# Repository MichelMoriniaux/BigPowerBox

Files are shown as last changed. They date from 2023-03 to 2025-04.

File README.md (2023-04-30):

# BigPowerBox
 An open source power distribution switch for 12V DC applications
- [BigPowerBox](#bigpowerbox)
  - [Introduction](#introduction)
  - [USB ports or rather, the lack of](#usb-ports-or-rather-the-lack-of)
  - [File contents](#file-contents)
  - [Requirements](#requirements)
    - [Operate](#operate)
    - [Build](#build)
  - [PCB picture](#pcb-picture)
  - [Enclosure](#enclosure)
  - [N.I.N.A Screencap](#nina-screencap)
- [Acknowledgements](#acknowledgements)

## Introduction
Astrophotography is great hobby but some of its drawbacks are that you often need to hang out in the cold and drive to far away places to find dark skies. Both of these problems can be solved with remote observing, either from your comfortable office while your telescope is out in the cold backyard or far away in a remote observatory. In both cases you may need to power-off-and-on-again equipment to reboot it or simply to shut down your observatory for the day. To this end you can buy specialized equipement to do so or build your own! 

But why would you build vs buy??? 

For one, specialized power boxes are usually expensive (400 to 1000 USD range) and may not provide the features you actually need. Secondly - and most importantly in my case - all the commercial offerings absolutely insist on providing the output ports on 2.5mm barrel connectors. These connectors' fit are notoriously unreliable and in the case of astronomy with a moving mount pulling and tugging on cables is a recipe for frustration and lost imaging time.  
The *BigPowerBox* aka *PowerBox Exxxtreme* is built with versatility, reliability and scale in mind. The output connectors are all GX-12 aviation plugs, most high quality mounts on the market use these plugs as they *screw-on* and provide a very secure connection. A few years back, frustrated by disconnects during slews I replaced all the connectors ( including serial and USB ) with Gx-12s in my EQ-6, this was the origin of my love for these connectors.  
I also found that the commercial powerboxes were also limited in ports, so I went overboard and crammed as much as I could in a small footprint. The box provides natively 14 12V output ports, you could customize these with small buck converters to 5V or whatever voltage mix you would want. There is enough space in the enclosure for that and as an example I have used 2 of the 12v switchable ports to feed at [5v buck converter](https://www.amazon.com/gp/product/B0BHR3RYPS) and a [3A capable USB port](https://www.amazon.com/gp/product/B087RHWTJW) ( great to power a ASIAir or other Raspberry Pi based computers for eg ) 

Building this box was also an exercise in learning a new hobby: electronics design. I'm a CS engineer, not EE. I have built a lot of Arduino based tools ( flip flat panel, temperature regulators for my cheap wine fridges, my own 3d printer and a slew of home automation devices ) but never a device that needed me to read datasheets for. So even though I tested the device I guarantee nothing and do not blame me if it burns down your stuff. I release this as Open Source Hardware with a CERN license so that real HW designers can improve on my base design and point out my noob mistakes. I had my boards fabricated by JLCPCB for about 100USD a piece.

This repo contains all the necessary files to build and control a power box with the following features

- 12V dc 30A input through an XT-60 port
- 14 power ports
  - 2 always-ON ports up to 10A each - use these to connect your NUC or other PC as well a s USB hub
  - 8 switchable ports up to 6.5A each - connect your cameras, mount, focusers, rotators, dust-caps, etc...
  - 4 PWM ports up to 6.5A each - dew-heaters, flat panels or add filtering caps if you want to make them adjustable voltage ports
- expansion RJ12 port for i2c accessories
  - currently only SHT31 Temperature/Humidity probe is supported
- reverse polarity protection on input and outputs
- overcurrent protection
- configurable overvoltage protection ( set in code at 14.4V )
- input Current and voltage measurement
- output current measurement on all ports
- dew heater control based on temp/humid sensors 

## USB ports or rather, the lack of
All commercial powerboxes have an integrated USB hub, so why does my box not have one? TBH I originally wanted to also have an awesome USB3.1 Gen 2 hub with plenty of ports, but have you ever tried to design one? One of the goals was to spend less building this than buying a commercial box and from my research - and the laughs of my friends who are in hardware - I deduced that I would have spent much more just iterating to get the high speed USB hub working. It's a completely different ball game to build a reliable, superspeed USB hub, especially when astrophotographers looove long usb cables. So I decided to leave that project for another day and just buy an industrial hub.

## File contents
Please read the Readme in each folder for more details

- Arduino
  - BigPowerBox   -  Arduino firmware
- Drivers
  - BigPowerSwitchServer  -  Visual Studio 22 solution to build the ascom COM server driver
  - IndiBigPowerSwitch - TODO: Indi driver
- Hardware
  - Enclosure - Case STL + link to Fusion 360 model
  - PCB - Gerber files to have the board manufactured, BOM and placement files, Electric schematics, EasyEDA project files

## Requirements
### Operate
To Operate this device you will need the following
- Windows
  - Ascom platform
  - FTDI driver ( my arduino implementation uses a FT232 chip)
  - Astro sequencer ( I tested on N.I.N.A but this should also work on SGP and others )
  - download the ascom installer from the [releases](https://github.com/MichelMoriniaux/BigPowerBox/releases) tab and run it, the Switch will be available in your Ascom chooser under "ShortCircuit.BigPowerSwitch"
- Linux (TODO)
  - Indi platform
  - Kstars / Ekos

### Build
To build the device you will need:
- a spare arduino with an ICSP cable ( to burn the bootloader ). I used an arduino nano from which I cut the traces to the RESET pin on the ICSP header and soldered it to pin D10. Replaced the header with a set of pogo pins and done.
  - [Pogo pins](https://www.amazon.com/gp/product/B075Q25BK3)
  - [Arduino](https://www.amazon.com/gp/product/B0713XK923)
- Arduino dev environment  
- 3d printer + slicer
- [M3 8mm flat head bolts](https://www.amazon.com/gp/product/B07WZL3Z7H)
- [M3 inserts](https://www.amazon.com/gp/product/B08YYGRCBG)
- [GX12 connectors](https://www.amazon.com/gp/product/B01MPXOOI3)
- [SHT31](https://www.amazon.com/gp/product/B07ZSZW92J)
- [XT60 connectors](https://www.amazon.com/gp/product/B07Q2SJSZ1)  

To Customize the software you will additionally need:
- for ASCOM the Ascom dev platform and Visual Studio 2022
- for Linux Indi and build-tools  

To customize the hardware you will also need:
- EasyEDA

## PCB picture
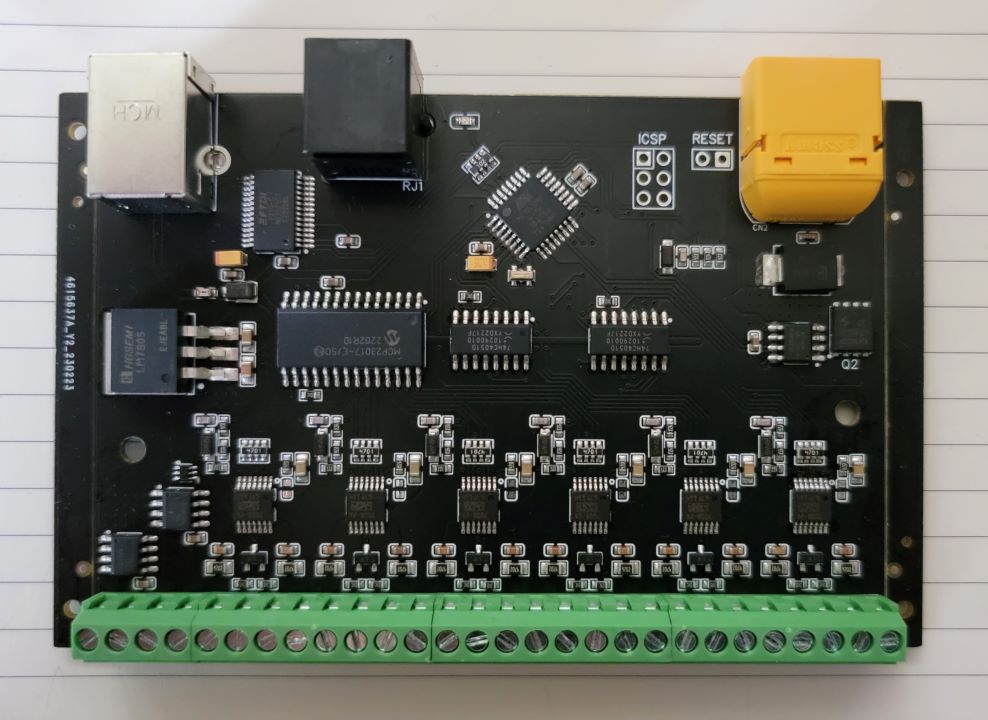
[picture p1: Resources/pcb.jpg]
PCB Picture


## Enclosure
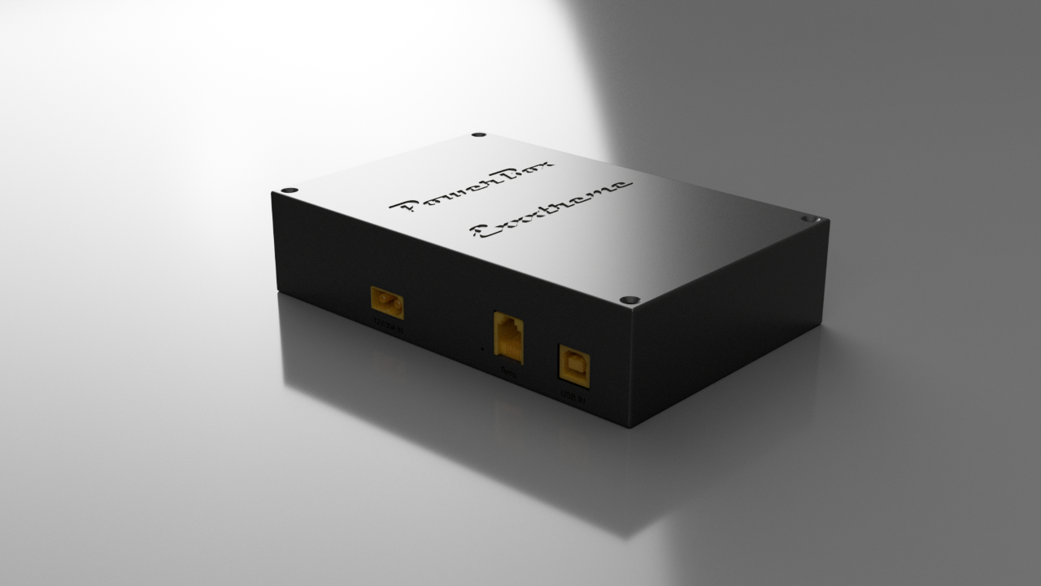
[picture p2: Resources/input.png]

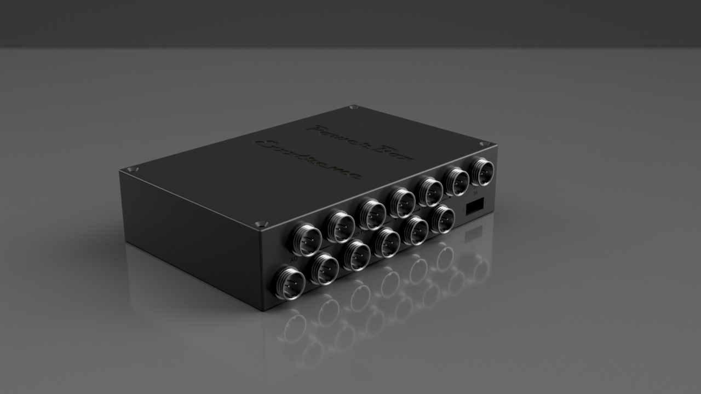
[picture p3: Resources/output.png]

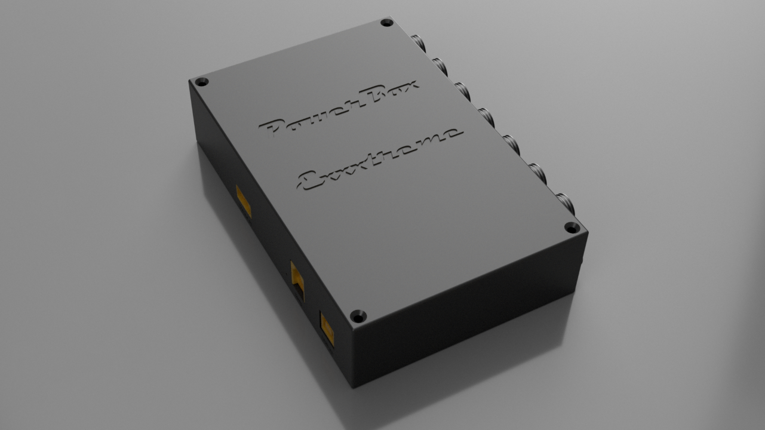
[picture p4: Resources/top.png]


## N.I.N.A Screencap
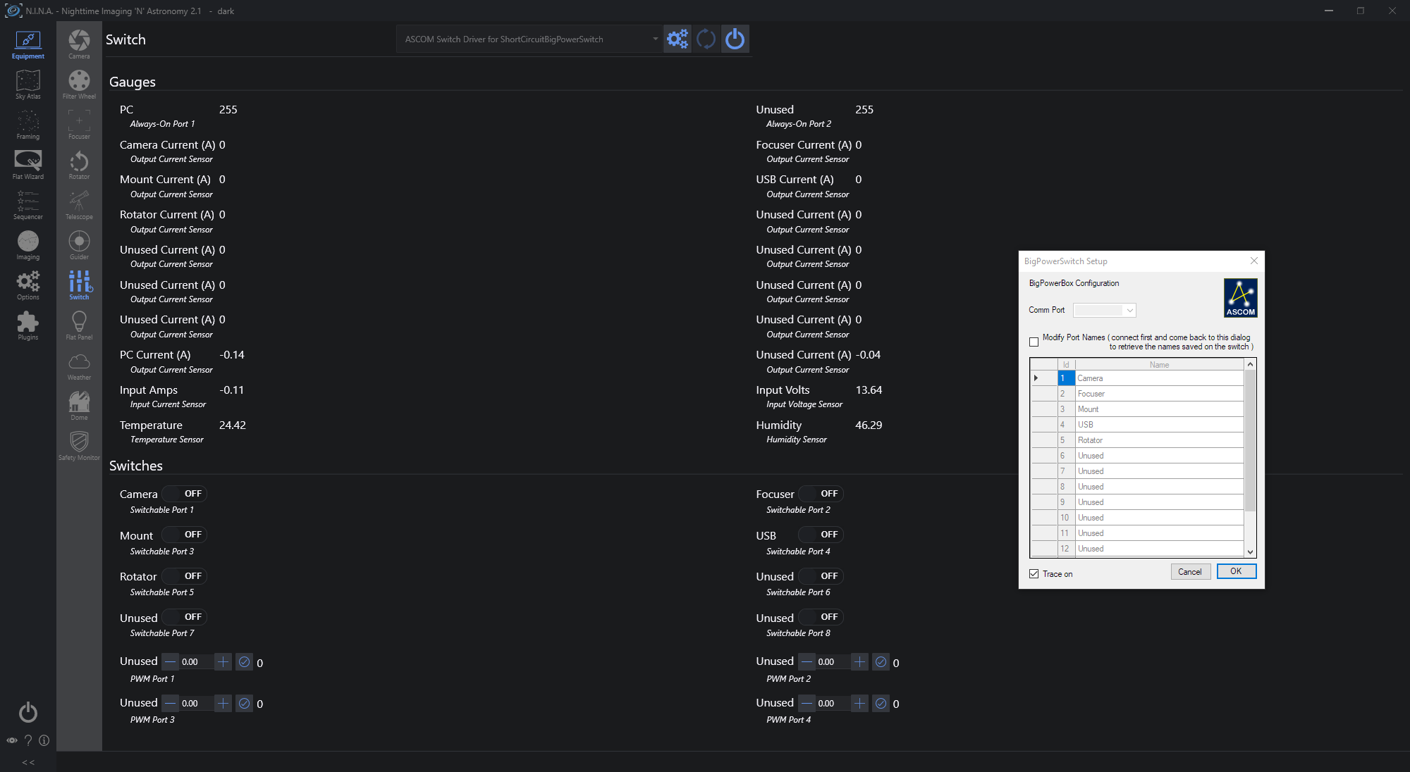
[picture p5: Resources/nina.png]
screencap


# Acknowledgements
The first electronic project I built and customized was [MyfocuserPro2](https://sourceforge.net/projects/arduinoascomfocuserpro2diy/) by [Robert Brown](rbb1brown@gmail.com), reading and customizing the code for my version of the focuser introduced me to Arduino programming and pushed me to build my 3d printer. I encourage you to go check that project out.

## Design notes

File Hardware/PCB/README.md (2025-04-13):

# BigPowerBox
 An open source power distribution switch for 12VDC applications

# Introduction
The BigPowerSwitch is a 12V DC distribution switch that allows individual control and measurement of 14 DC ports. It should be able to drive 30A of current to the output ports with a maximum of 6.5 amps on each port. It is not recommended to drive the board that high as the thermals have not been tested to that level. It should function correctly for the usual loads pulled by astronomy cameras and accessories.

# Implementation
The BigPowerSwitch has the following components:
- PCB
  - 4 layer 
    - top layer signal + GND flood
    - uninterrupted 1 Oz 12V flood ( do a 2Oz if you can. Also might be better to swap this one with plane 3 for future add of USB3.1 - impedance )
    - uninterrupted 1 Oz GND flood
    - bottom layer via signals + GND flood
- Input stage
  - XT60 connector for 30A capability, polarity protection and snug connection. Also pretty much the standard for RC stuff so I have good experience with and love those connectors. If it can survive sustaining multiple Gs followed by a crash while pulling 30Amps it should work for astro gear. I would have prefered a screwable connector but could not find a good option, also having a different polarized connector can prevent mistakes.
  - 33V TVS diode
  - 20V 60A Mosfet to protect against reverse voltage input ( backwards connection to a battery )
  - 30A Ammeter feeding a dedicated ADC port on the microcontroller ( In Amps )
  - 15V to 5V voltage divider feeding a dedicated ADC port in the microcontroller ( In Volts )
- Output stages
  - uses the 12V plane
  - 6 Infineon BTS7008-2EPA 2 channel high switches
    - 4 for switch ports ( 8 ports ) enable pins through port expander MCP23017
    - 2 for PWM control ( 4 ports ) enable pins directly driven by microcontroller digital PWM pins
    - diagnostic pin for Current sensing feeding a multiplexed ADC pin on the microcontroller
    - I chose Infineon as they seem to be an automotive supplier and thus heavier duty than my original thought of using TI backplane chips.
  - 2 10A Ammeters for always-on ports feeding a multiplexed ADC pin on the microcontroller. Here I used CrossChip, the LCSC part choser only gave this reference for a 10A ammeter, datasheet needed to be translated as not available in English...
  - 5V/1A voltage regulator for VCC
  - DB125 screw terminals
- Control
  - Arduino nano V3 implementation
    - Atmel 328P microcontroller
    - FT232RL USB serial controller
    - 1 power LED ( yep Tx and Rx leds are just luminous noise, even this one is overkill )
    - ICSP port
    - i2c bus with RJ12 output for temp/humid sensor
  - MCP23017 i2c I/O port expander
    - controls the enable pins of the on/off switches (EN0 and EN1 on BTS7008-2EPA)
    - uses the 8 GPA pins. 8 pins (GPB) unused
  - 2 74HC4051D multiplexers
    - one for output: distributes the DSEL signal to select the diagnosed port on the Infineon switches
    - one for input: collects the diagnostic signal from the Infineon switches and output port ammeters to a single ADC pin on the microcontroller
    - both function in parallel driven by the same 3 control pins on the microcontroller

All resistor and capacitor values were chosen based on datasheet recommendations and prototyping sample board specifications. I'm pretty sure I could have used more decoupling caps.

The board was designed in EasyEDA with the LCSC for JLCPCB parts catalog and fabricated by JLCPCB. This PCB prototyper has a minimum of 5 boards runs for PCB production and 2 boards for assembly, the run for 5 boards and 2 assemblies was less than 250USD delivered.

I have provided in this repo:
- the Gerber files to produce the PCB
- the EasyEDA source files with the schematics and PCB layout
- BoM file
- placement file for assembly

Once the board delivered, you will need to flash a bootloader onto it. There are a lot of guides on the web as how to do this but it essentially boils down to: in the Arduino IDE, configure the board as an "Arduino Nano", processor as "ATMega 328P" and Programmer as "Arduino as ISP", connect the ISCP cable from your burner and click "Burn Bootloader"  
You can build a quick and dirty burner from an arduino nano board, a 2cm piece of wire, a knife and some pogo pins.  

# PCB image and Finished product
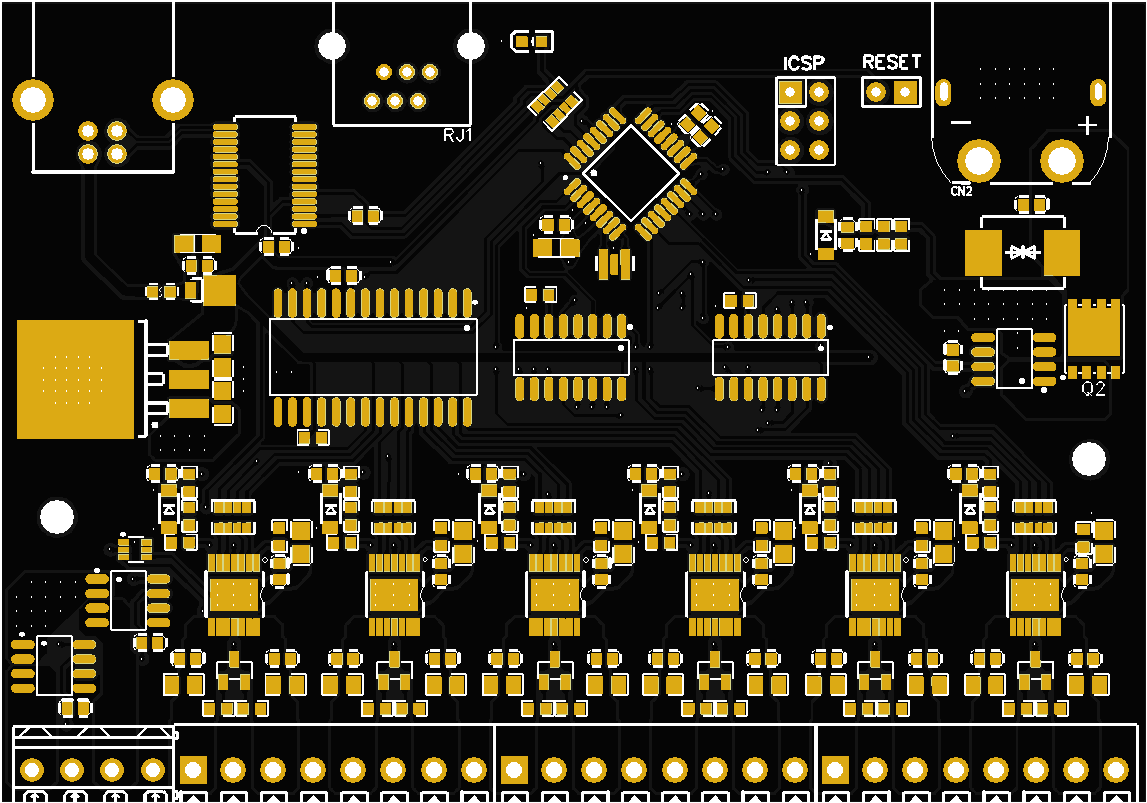
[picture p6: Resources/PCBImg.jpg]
PCB

PCB Picture

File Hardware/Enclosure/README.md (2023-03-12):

# BigPowerBox
 An open source power distribution switch for 12VDC applications

Here you will find STLs for the box and lid.  
The box is configured to be printer friendly and has 13 GX12 ports and one USB port.  
2 Allways-on, 6 Switch ports, 4 PWM ports, 1 5V port, 1 USB port (power only)

The Enclosure Fusion360 source file is [here](https://a360.co/3Ja40tm)

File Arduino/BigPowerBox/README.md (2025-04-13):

# BigPowerBox Arduino Firmware
An open source power distribution switch for 12VDC applications

Please see the README for the hardware before reading this file
- [BigPowerBox Arduino Firmware](#bigpowerbox-arduino-firmware)
- [Introduction](#introduction)
- [Logic](#logic)
- [Required Libraries](#required-libraries)
- [Modularity](#modularity)
- [Hardware expansion](#hardware-expansion)
- [Temperature probes](#temperature-probes)
- [Storage](#storage)
- [Command Protocol](#command-protocol)
  - [Available commands:](#available-commands)
- [Building Options](#building-options)

# Introduction
This is the firmware for the BigPowerBox. It manages input commands and provides status updates to the driver. The Powerbox can function standalone without a USB connection to a host.

# Logic
The firmware for the power box is built as a state machine.
The state machine starts in an ***idle*** state. Every loop cycle it verifies if there is a command in queue and processes it.
Every *REFRESH* milliseconds the state changes to ***read***.
In ***read*** state the firmware polls the arduino ADC pins for values and verifies if the input voltage is below the shutdown value. If the input voltage is above, it calls a function to shutdown all the switchable and PWM output ports.
Once the values are read the FSM moves to ***dew*** state where it reads temperatures and adjusts the configured PWM ports. Once this is done the FSM goes to the ***swap*** state and uses the PCB's multiplexers to select the next port to read the output Current from. Once the swap is executed the FSM returns to ***idle*** state.

When a command is sent to the controller it is pushed into a LIFO queue. At each loop the code checks if there are commands in queue and if yes pops one command and processes it.

# Required Libraries
To build you will need to install the following packages into your Arduino Libraries:  
***EEPROM***      should be included by default in your base install  
***Wire***        One Wire Lib for i2c  
***Adafruit_MCP23XXX*** to operate the MCP23017 i2c controlled I/O expander on the board  
***Adafruit_SHT31*** for SHT3x temperature/humidity sensor  
***Adafruit_AHTX0*** for the cheap AHT10 temperature/humidity sensor
***Adafruit_BME280*** for the BME280 temperature/humidity/pressure sensor
***SparkFun_I2C_Mux_Arduino_Library*** for the PCA9548A i2c multiplexer
***PIDController*** for the PWM dew heater PID control
***[MemoryFree](https://github.com/mpflaga/Arduino-MemoryFree)*** only for debug purposes ( used it to make sure I was not fragmenting the memory )

# Modularity
I originaly wanted this code to be generic and customizable for any board layout by only customizing *board.h*. This is still a work in progreass as I took shortcuts to get a working prototype out. The main variable is the boardSignature string that defines the list of ports, their order and their types. This also defines how the status string is presented. The following comment in *board.h* defines the boardSignature:

    // Board signature
    //  s: arduino addressable switchable port
    //  m: multiplexed switchable port
    //  p: pwm port
    //  a: Allways-On port
    //  f: Temp/Humidity probe
    //  g: Temp/Humidity/pressure probe
    //  t: temperature probe
    //  h: humidity probe
    // always-on ports always last followed by t then h
    const String boardSignature = "mmmmmmmmppppaath";

# Hardware expansion
The board is expandable through the exposed i2c interface via the RJ12 connector. Currently are supported BME280, SHT31, AHT10 and the PCA9548A i2c multiplexer, allowing you to build complex temperature probe setups. The setups allow you to either have a simple Temperature / Humidity sensor to turn on the configured PWM ports when the temperature dips below the dewpoint or have a more complex setup with dedicated temperature feedback for each PWM port (adjusting each port output to maintain a configurable temperature offset above the dewpoint).  
The RJ12 port has the following pinout  

    pin 1: NC
    pin 2: GND
    pin 3: SDA
    pin 4: SCL
    pin 5: 5V
    pin 6: NC

# Temperature probes
The board will detect i2c temperature probes at boot. The first probe found will always be the global environment probe, each additional probe found will be assigned to the PWM ports in ascending order for PID control. the order of preference for primary probe is BME280, SHT31, AHT10

# Storage
The EEPROM on the Atmel328 is 1024 bytes and it's cells are limited to 100k writes.  
We reserve the first 16x14 bytes (224 bytes) to store the port names ( this includes the trailing '\0' so port names are limited to 15 chars). We don't expect these to change often so no special scheme is implemented to save write cycles. There is no provision to flag a name as valid, we could have used the first byte and limit the name to 14 chars.  
Starting at byte 224 we store the configuration. The configuration is 18 bytes long and contains the port statuses and a validity flag. The config is saved every time a port changes state. To limit EEPROM wear we write the config to the next 18 following bytes. At startup we need to find this config so that is where the validity flag comes into play.

# Command Protocol
Every command and it's reply starts with a '>' and ends with a '#' 
newlines and carriage returns are not required, fields inside commands are separated by ':' characters

example commands:
|send|reply|
|---|---|
|`>P#`|`>POK#`|
|`>M:01:Hello World#`|`>MOK#`|
|`>N:01#`|`>N:01:Hello World#`|

## Available commands:
|literal|command|response|description|
|---|---|---|---|
|`P`|Ping|`POK`|Ping the device, can be used for autodiscovery of comm ports or to maintain a keepalive for a watchdog|
|`D`|Discover|`D:<Name>:<Version>:<Signature>`|Discover the device and capabilities, returns the following fields
|||`<Name>`|the device name|
|||`<Version>`|hardware revision|
|||`<Signature>`|a string representing the device capabilities|
|`S`|Status|`S:<statuses>:<currents>:<Ic>:<Iv>:<t>:<h>`|The status of all ports and measurements|
||||`<statuses>` is a colon separated list of statuses|
|||| 0: switchable port Off|
|||| 1: switchable port On or always-on port|
|||| 000 to 255: PWM port duty-cycle level|
||||`<currents>` same number of fields as `<statuses>` each indicating the output current in A|
||||`<Ic>` Input Current in A|
||||`<Iv>` Input Voltage in V|
||||`<t>` temperature in C Optional ( only present if the hardware is detected )|
||||`<h>` humidity in % Optional ( only present if the hardware is detected )|
||||`S:0:1:0:1:0:1:005:200:1:1:0.00:5.25:0.00:3.12:0.00:7.09:0.10:2.3:0.00:0.00:15.46:12.4:8.1:75.0`|
||||the example matches the ouput for the signature string example above: 10 status fields `ssmmmmppaa` followed by 10 current fields in the same order followed by the input current, input voltage, temp and humid|
|`N:<dd>`|Get port Name|`N:<dd>:<portname>`|get the stored port name for port `<dd>` ( 2 digit number 0-padded eg `05` or `12`)|
||||`<portname>` 15 character max port name|
|`M:<dd>:<portname>`|Set port name|`MOK`|set the port name `<portname>` of port `<dd>`|
|`O:<dd>`|ON|`OOK`|Turn port `<dd>` On|	
|`F:<dd>`|OFF|`FOK`|Turn port `<dd>` Off|
|`W:<dd>:<level>`|set PWM level|`WOK`|set the port `<dd>` to `<level>` level is an integer between 0 (Off) and 255 (full On)|
|`C:<dd>:<mode>`|set PWM port mode|`COK`|set the port `<dd>` to `<mode>` mode is an integer: |
||||0: pwm adjustable port|
||||1: behave like and ON/OFF port|
||||2: dewpoint mode: when the temperature measured by the reference probe dips below the dewpoint turn on the port to the preset value, turn it off if the temperature rises above the dewpoint. requires a connected temp/humid probe|
||||3: temperature controlled mode: the port has a dedicated temperature probe that allows to turn off the port when the temperature of the dedicated probe rises above the dewpoint |
|`G:<dd>`|get PWM port mode|`G:<dd>:<mode>`|get `<mode>` of the port `<dd>`|
|`T:<dd>:<temp>`|set a positive temperature offset for the dew control fir each PWM port|`TOK`|set `<temp>` offset for port `<dd>`|
|`H:<dd>`|get the temperature offset for a port|`H:<dd>:<temp>`|get `<temp>` offset of the port `<dd>`|

# Building Options
to build and flash the firmware you will need the following:
a pogo pin programmer for the initial bootflash, see the instructions in the PCB folders
For the firmware use the same option as for an Arduino Nano:
- Board: Arduino AVR Boards / Arduino Nano
- Processor: ATMega328P

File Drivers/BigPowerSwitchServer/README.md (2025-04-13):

# BigPowerBox ASCOM Driver
An open source power distribution switch for 12VDC applications

Please see the [README for the firmware](https://github.com/MichelMoriniaux/BigPowerBox/blob/main/Arduino/BigPowerBox/README.md) before reading this file

- [BigPowerBox ASCOM Driver](#bigpowerbox-ascom-driver)
- [Introduction](#introduction)
- [Principles of Operation](#principles-of-operation)
- [Installing the driver](#installing-the-driver)
- [Building the driver](#building-the-driver)

# Introduction
This Ascom driver will work with the open source hardware BigPowerBox or any hardware that respects the BigPowerBox Protocol.

The driver exposes all the power ports and sensors of the device via Ascom Switches. The polling frequency will depend on the client software. For eg. N.I.N.A polls each switch's name and value every 2sec.

The configuration pane allows to set the names of the power ports. Note that upon launch the configuration dialog does not know the names saved on the device, please set the comm port and press OK, connect and then re-access the configuration dialog. The names saved on the device will be populated and will be editable. Any modifications done to the port names prior to connecting to the device will be discarded. Note that the first time you read the port names on a brand new board you will get garbage as the firmware does not initialize the EEPROM at initial boot. Actually there is no mechanism for the firmware to know if a valid name is stored.

# Principles of Operation
The driver is built as a COM server. This allows multiple clients to connect and control the switches concurrently.
The server driver is started when the first client connects. The server connects to the hardware via a USB serial port, retrieves the board description and populates the internal data structures.  
The client polling and hardware polling are decoupled for performance reasons. Once connected the hardware driver starts a polling thread that polls the hardware ( status command ) every ***UPDATEINTERVAL*** seconds ( 2 in the Release version) and updates the internal data structures. When a client requests a port value or status the hardware driver responds with the value stored in the data structure. When a client wants to update a switch the command is directly forwarded to the hardware.  
So in short *Read* operations are asynchronous and *Write* oprations are synchronous.  
The server maintains a list of clients and shuts down once all clients have disconnected.  
You can now configure the PWM ports into 4 modes:
- 0: normal PWM mode
- 1: on/off mode this requires a connect/deconnect in N.i.n.a. for the UI to update
- 2: dew heater mode, when the ambient temperature dips under the dewpoint the associated port will turn on to a preset value
- 3: temperature control, this requires an additional temperature probe for the dew heater and will control the port according to a PID algorithm to set the temperature to dewpoint + configurable offset

# Installing the driver 
Downlad the installer from the [releases](https://github.com/MichelMoriniaux/BigPowerBox/releases) tab and run it, it should register the server and make the driver available in the ASCOM choser. 

# Building the driver
Open the solution in Visual Studio 2022 and press `CTRL+B` the driver should build.  
Open a command prompt and run the local server exe `ASCOM.ShortCircuitBigPowerSwitch.exe` with the `/regserver` parameter (requires admin privileges), which will create the entry that appears in the ASCOM Chooser. This registration only needs to be done once on each PC. Use the `/unregserver` parameter to unregister the server when no longer required. Never use `REGASM` on the local server executable.
Even better modify the included .iss file to match your paths and compile your own installer, .iss files are used with Inno Setup Compiler

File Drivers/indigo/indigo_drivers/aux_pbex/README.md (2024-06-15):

# BigPowerBox driver

https://github.com/MichelMoriniaux/BigPowerBox

## Supported devices
* BigPowerBox

## Supported platforms

This driver is platform independent.

## License

INDIGO Astronomy open-source license.

## Use

indigo_server indigo_aux_pbex

## Status: Stable

Tested with physical device.

## Build instructions
* this driver depends on indigo server. The indigo server code can be downloaded from the github link below -

https://github.com/indigo-astronomy/indigo/tree/master

Alternatively, the binaries are available here -

https://www.indigo-astronomy.org/downloads.html

Additionally, gcc compiler and other build toold are also required.

Once the indigo environment is setup, follow these steps to build the indigo_aux_pbex (BigPowerBox) driver -
* start by compiling indigo_drivers/aux_pbex/indigo_aux_pbex_main.c

  gcc -c indigo_aux_pbex_main.c

  if instead of binaries indigo server code was built then, libindigo.so needs to be added to the LD_LIBRARY_PATH.

* build a shared library

  sudo gcc -fPIC -shared -o /usr/lib/indigo_aux_pbex.so indigo_aux_pbex.c

  by default libindigo exists in /usr/lib/. If the code was built from scratch then the relative library path would be /indigo/build/drivers.

* build executable 

  sudo gcc -o /usr/bin/indigo_aux_pbex indigo_aux_pbex_main.o -l:libindigo.so -l:indigo_aux_pbex.so -lm

* run/load the driver 

  if indigo server was installed directly just run -
  indigo_server indigo_aux_pbex

  if indigo server is built from scratch load the driver either from indigo control panel or from the indigo config web page.

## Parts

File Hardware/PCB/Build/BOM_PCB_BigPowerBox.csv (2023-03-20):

ID | Name | Designator | Footprint | Quantity | Manufacturer Part | Manufacturer | Supplier | Supplier Part | Price
1 | 100nF | C3,C31,C29,C28 | C0603 | 4 | CC0603KRX7R9BB104 | YAGEO(国巨) | LCSC | C14663
2 | DS1133-S60BPX | RJ1 | RJ11-TH_DS1133-S60BPX | 1 | DS1133-S60BPX | CONNFLY | LCSC | C77859 | 0.026
3 | HY15P03C2 | Q2 | DFN-8_L5.9-W5.2-P1.27-LS6.2-BL | 1 | HY15P03C2 | HUAYI(华羿微) | LCSC | C123687
4 | XT60PW-M | CN2 | CONN-TH_XT60PW-M | 1 | XT60PW-M | AMASS(艾迈斯) | LCSC | C98732 | 0.075
5 | 4.7kΩ | RN7,RN6,RN5,RN4,RN2,RN3 | RES-ARRAY-SMD_0603-8P-L3.2-W1.6-BL | 6 | 4D03WGF4701T5E | UNI-ROYAL(厚声) | LCSC | C66697 | 0.002
6 | 16MHz | X1 | OSC-SMD_3P-L3.2-W1.3-P0.95-L | 1 | CSTCE16M0V53-R0 | muRata(村田) | LCSC | C32180 | 0.037
7 | 670688001 | USB1 | USB-B_TH_670688001 | 1 | 670688001 | MOLEX | LCSC | C490687 | 0.16
8 | DB125-3.5-4P-GN | U24 | CONN-TH_DB125-3.5-4P-GN | 1 | DB125-3.5-4P-GN-S | DIBO(地博电气) | LCSC | C2757925 | 0.044
9 | LM7805S/TR | U22 | TO-263-3_L8.6-W10.2-P2.54-LS14.4-BR | 1 | LM7805S/TR | HGSEMI(华冠) | LCSC | C507146 | 0.04
10 | FT232RL-REEL | U21 | SSOP-28_L10.2-W5.3-P0.65-LS7.8-BL | 1 | FT232RL-REEL | FTDI(飞特帝亚) | LCSC | C8690 | 0.937
11 | ATMEGA328P-AU | U20 | TQFP-32_L7.0-W7.0-P0.80-LS9.0-BL | 1 | ATMEGA328P-AU | MICROCHIP(美国微芯) | LCSC | C14877 | 0.499
12 | MCP23017T-E/SO | U19 | SOIC-28_L17.9-W7.5-P1.27-LS10.3-BL | 1 | MCP23017T-E/SO | MICROCHIP(美国微芯) | LCSC | C629440 | 0.407
13 | DB125-3.5-8P-GN-S | U33,U14,U13 | CONN-TH_8P-P3.50_DORABO_DB125-3.5-8P-GN-S | 3 | DB125-3.5-8P-GN-S | DIBO(地博电气) | LCSC | C5184954 | 0.102
14 | 74HC4051D,653 | U17,U12 | SOIC-16_L9.9-W3.9-P1.27-LS6.0-BL | 2 | 74HC4051D,653 | Nexperia(安世) | LCSC | C9386 | 0.041
15 | CC6900SO-30A | U11 | SOP-8_L4.9-W3.9-P1.27-LS6.0-BL | 1 | CC6900SO-30A | CrossChip(成都芯进) | LCSC | C355193 | 0.114
16 | CC6900SO-10A | U8,U7 | SOP-8_L4.9-W3.9-P1.27-LS6.0-BL | 2 | CC6900SO-10A | CrossChip(成都芯进) | LCSC | C286005 | 0.126
17 | BTS70082EPAXUMA1 | U6,U5,U4,U3,U2,U1 | PG-TSDSO-14_L4.9-W3.9-P0.65-LS6.0-BL-EP | 6 | BTS70082EPAXUMA1 | Infineon(英飞凌) | LCSC | C2150060 | 0.901
18 | 1K | RN1 | RES-ARRAY-SMD_0603-8P-L3.2-W1.6-BL | 1 | YC164-JR-071KL | YAGEO(国巨) | LCSC | C93675 | 0.001
19 | 47kΩ | R59,R52,R51,R50,R39,R38,R37,R36,R35,R34,R33,R29 | R0805 | 12 | 0805W8F4702T5E | UNI-ROYAL(厚声) | LCSC | C17713
20 | 47Ω | R49,R48,R43,R42,R41,R40 | R0603 | 6 | 0603WAF470JT5E | UNI-ROYAL(厚声) | LCSC | C23182
21 | 10kΩ | R47,R46,R45,R44,R31,R28,R27,R26,R25,R24,R23,R22,R21,R16,R12 | R0603 | 15 | 0603WAF1002T5E | UNI-ROYAL(厚声) | LCSC | C25804
22 | 1.2kΩ | R74,R71,R68,R65,R32,R11 | R0603 | 6 | 0603WAF1201T5E | UNI-ROYAL(厚声) | LCSC | C22765
23 | 4.7kΩ | R73,R72,R70,R69,R67,R66,R64,R63,R62,R61,R15,R14,R13,R10,R9 | R0603 | 15 | 0603WAF4701T5E | UNI-ROYAL(厚声) | LCSC | C23162
24 | PUMD3,125 | Q1 | SOT-363_L2.0-W1.3-P0.65-LS2.1-BL | 1 | PUMD3,125 | Nexperia(安世) | LCSC | C553517 | 0.009
25 | KT-0603R | LED1 | LED0603-R-RD | 1 | KT-0603R | null | LCSC | C2286
26 | MF-FSMF050X-2 | F1 | F0603 | 1 | MF-FSMF050X-2 | BOURNS | LCSC | C210357 | 0.006
27 | SS1P3L-M3/84A | D11,D3 | DO-220AA_L3.4-W2.0-LS3.9-RD | 2 | SS1P3L-M3/84A | VISHAY(威世) | LCSC | C2875475 | 0.049
28 | BAW56_C181106 | D10,D9,D8,D7,D6,D5 | SOT-23-3_L2.9-W1.3-P1.90-LS2.4-BR | 6 | BAW56 | Hottech(合科泰) | LCSC | C181106 | 0.002
29 | BZT52C5V1_C2891773 | D16,D15,D14,D13,D12,D4,D2 | SOD-123_L2.7-W1.6-LS3.7-R-RD | 7 | BZT52C5V1 | YONGYUTAI(永裕泰) | LCSC | C2891773 | 0.002
30 | SMCJ33CA_C310048 | D1 | SMC_L6.9-W5.9-LS7.9-BI | 1 | SMCJ33CA/TR13 | Brightking(君耀电子) | LCSC | C310048 | 0.019
31 | 4.7uF | C30,C25 | CASE-A_3216 | 2 | TAJA475K016RNJ | Kyocera AVX | LCSC | C7187 | 0.015
32 | 100nF | C47,C20,C19,C18,C17,C16,C15 | C0805 | 7 | CC0805KRX7R9BB104 | YAGEO(国巨) | LCSC | C49678 | 0.001
33 | 330nF | C46 | C0805 | 1 | 0805B334K500NT | FH(风华) | LCSC | C1740 | 0.003
34 | 100pF | C38,C37,C36,C35,C34,C5 | C0603 | 6 | CL10C101JB8NNNC | SAMSUNG(三星) | LCSC | C14858 | 0.001
35 | 4.7nF | C24,C23,C22,C21,C14,C13,C12,C11,C10,C9,C7,C6 | C0603 | 12 | 0603B472K500NT | FH(风华) | LCSC | C53987
36 | 1uF | C45,C44,C43,C33,C32,C27,C26 | C0603 | 7 | CL10A105KB8NNNC | SAMSUNG(三星) | LCSC | C15849 | 0.001
37 | 1nF | C1 | C0603 | 1 | CL10B102KB8NNNC | SAMSUNG(三星) | LCSC | C1588 | 0.001

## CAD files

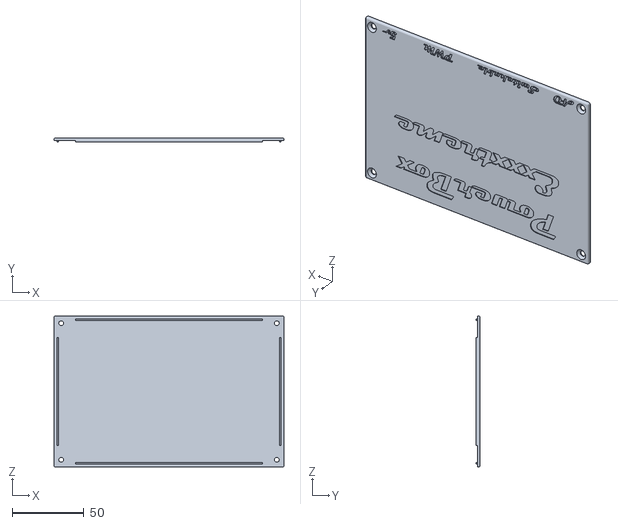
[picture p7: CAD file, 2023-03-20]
Hardware/Enclosure/Lid.stl
160.0 x 3.00 x 105.0

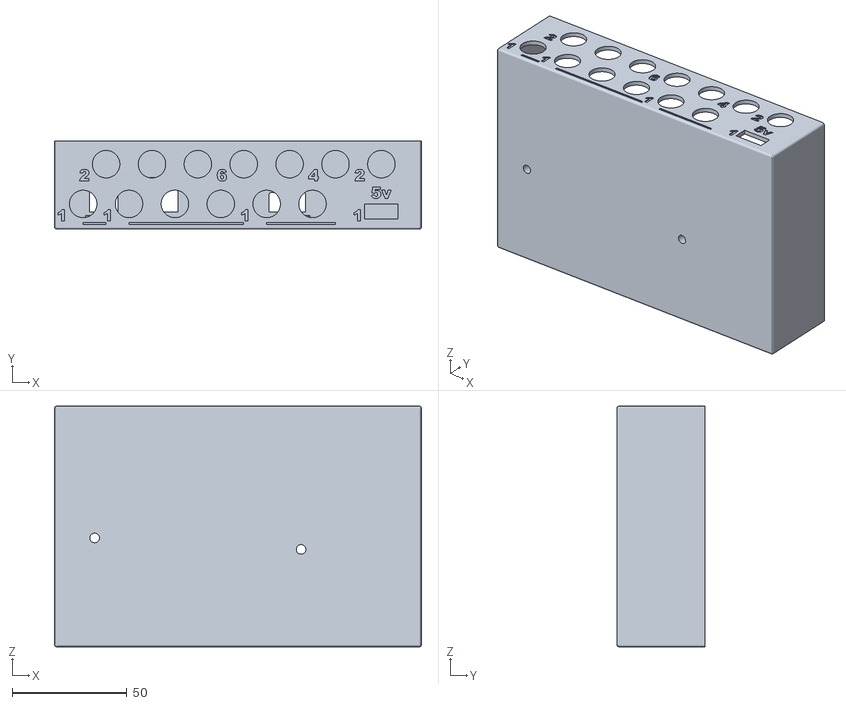
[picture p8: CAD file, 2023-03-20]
Hardware/Enclosure/Box.stl
160.0 x 38.5 x 105.0

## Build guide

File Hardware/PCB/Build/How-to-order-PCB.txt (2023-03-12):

How to Order PCB

Please refer to:
https://docs.easyeda.com/en/PCB/Order-PCB

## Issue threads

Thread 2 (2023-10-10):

XT60 input pcb

beshanoe, 2023-10-10:
Hi! First of all, thanks for the amazing project! I'm thinking of building my own copy and have realized that I can't find that XT60 input group from the CN image
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

Is it custom made or can be bought as an assembly?

MichelMoriniaux, 2023-10-12:
Hi!
The small board your arrow is pointing to is a 12v to 5v USB-A buck
converter, 5$ on Amazon. It's an output to power a USB device like a Raspi
for eg.

The XT60 input is the big yellow thing on the mainboard

Michel

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

Closed 2024-05-27.

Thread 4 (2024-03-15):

Indi/Indigo support

rohan5sep, 2024-03-15:
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
Hi, thanks for sharing your work! I really like the project. I have ordered the PCB and planning to do the assembly myself. The only problem I am facing is that I don’t use ASCOM platform. Is there a plan to support indi? If not, can I contribute? I think can write indi/indigo driver — I will use your code as a reference. Also, could you please let me know the part number in the red rectangle? What does it do?

MichelMoriniaux, 2024-03-15:
Unfortunately I stopped using my Indi raspberry pi so never came around to build the driver. You are more than welcome to contribute!

MichelMoriniaux, 2024-03-15:
The part in the red rectangle is a 12v to 5v 5A buck converter, 2$ on Amazon. Not necessary but allows to have a 5v output if you need it

rohan5sep, 2024-03-15:
So both the green arrow and red rectangle are buck converters?

rohan5sep, 2024-03-15:
Oh got it the arrow one is usb and the red rectangle is 12v to 5v. Thanks

Closed 2024-05-27.

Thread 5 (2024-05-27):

PWM ports do not function as expected

rohan5sep, 2024-05-27:
The problem is because of following code in BigPowerBox.ino file --

The routines 1. setPWMPortLevel and 2. setDewPortLevel are incorrectly accessing "ports2Pin" array. The index "port" is zero based and so is ports2Pin[] array. But it is being incorrectly accessed like so: ports2Pin[port - 1]. Because of this, wrong pins are selected. Consequently, some pins work and others are not activated ever.

Changing   ports2Pin[port - 1] to  ports2Pin[port] fixed my problems.

MichelMoriniaux, 2024-05-27:
Thanks for the bug, that must've been a relic I forgot when I refactored the indices. I do not use that feature so missed it in testing

MichelMoriniaux, 2024-05-27:
Closed by mistake will do a PR and then close

rohan5sep, 2024-05-27:
Hi, i should be done with indigo driver code in few weeks. I am not sure where to submit the code. Can open a pull request here?

MichelMoriniaux, 2024-05-27:
Yes please do a PR

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

MichelMoriniaux, 2024-05-27:
fixed, PR published

Closed 2024-05-27.

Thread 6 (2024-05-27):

PWM ports will not turn ON when configured in dew heater mode.

rohan5sep, 2024-05-27:
This is because according to Clausius-Clapeyron equation condensation will occur when the relative humidity becomes 100%. At this point the air temperature will become equal to the dew point. The air temperature will never drop below the dew point. Therefore the code --

if(powerBoxStatus.temp < powerBoxStatus.dewpoint){...} is unlikely to be executed.

Better approach is to check/calculate the relative humidity instead. The ports can be turned ON if the relative humidity crosses a threshold say beyond 90%.

MichelMoriniaux, 2024-05-27:
good suggestion, effectively inverting the comparison might work. IIRC I went with dewpoint as some libraries do not expose RH but only dewpoint. But again I may be mistaken.
I live in a place where humidity is non-existent so I do not use the feature, I developed it for a user that requested it. if you can debug it and get it to work I will gladly accept a pull request.

rohan5sep, 2024-05-27:
Sure. I will create a pull request once I get it to work.

MichelMoriniaux, 2024-05-27:
created a PR with a minimal change that might work, may cause PID issues though, please take a look

rohan5sep, 2024-05-27:
> created a PR with a minimal change that might work, may cause PID issues though, please take a look

Will do.

rohan5sep, 2024-06-11:
Hi, I have opened a pull request that has indigo driver code and the firmware fix for the dew heater and temperature control. I tested the dew heater and it works fine. Will test PID when I have the parts. Did you get a chance to look at the files?

rohan5sep, 2024-06-15:
Closing as dew heater mode tested as fixed.

Closed 2024-06-15.

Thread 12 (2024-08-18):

Zero Vaules for temp sensor in NINA

TimSha2509, 2024-08-18:
I’ve built your powerbox and so far it worked flawlessly (thanks a lot for your amazing work!). However I just now decided to add a temperature probe and so far, Temp and Humidity will only be displayed as „0“ in NINA.

I have verified that the SHT31 sensor I’m using is actually working with the board by checking the device info in the Arduino IDE, where everything works great and the temperature is shown correctly.

I’ve already reinstalled the Ascom driver and also tried an older version to no avail so far. Any ideas what might cause this?

MichelMoriniaux, 2024-08-18:
Hello,
is the '0' value in the switches section? it should appear there not under weather.
I would need to go to my remote observatory ( next scheduled is in 2 weeks ) to do a test and confirm ( I do not have temp probes currently plugged in)

TimSha2509, 2024-08-18:
Hey!

Yes it’s listed as "Env Temp" etc. right where it also appears in your screenshot on the main page. Thanks a lot for your efforts!

rohan5sep, 2024-08-22:
While building this box I noted following: It takes over a minute for the values to be populated. Also, the temperature prob must be attached before booting up the power box.

Just sharing in case it helps...

Closed 2024-08-25.

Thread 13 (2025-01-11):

Assigned Temp Probe Implementation

TheGreatStar, 2025-01-11:
Hello, I would like to know how to assign a temperature probe to a dew heater port. I would be getting 2 SHT31_D. One would be stationed outside by the PowerBox, and the other would be placed inside my Dew Shield to read the temperature at the corrector plate.

How do I get this configured?

Closed 2025-01-29.

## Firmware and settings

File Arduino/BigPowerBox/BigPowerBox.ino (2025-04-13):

/* 
 *  BigPowerBox implementation
 *  License: GPLv3
 *  
 *  
 *  Michel Moriniaux 2023
*/

#include "myDefines.h"
#include "board.h"
#include <Arduino.h>
#include <EEPROM.h>                     // needed for EEPROM
#include <Wire.h>
#include <Adafruit_MCP23X17.h>
#include <Adafruit_SHT31.h>             // for SHT3x sensor attached to RJ12 port
#include <SparkFun_I2C_Mux_Arduino_Library.h>
#include <Adafruit_AHTX0.h>
#include <Adafruit_BME280.h>
#include <PIDController.h>

#ifdef DEBUG
#include <MemoryFree.h>
#endif

Adafruit_MCP23X17 mcp;
Adafruit_SHT31 sht31 = Adafruit_SHT31();
Adafruit_BME280 bme;
QWIICMUX imux;
Adafruit_AHTX0 aht10;
PIDController pid[4];   // up to 4 pid controllers, one for each PWM port

int probeCount = 0;
int memfree = 0;
int prevmemfree = 0;

const String programName = "BigPowerBox";
const String programVersion = "013";
const String programAuthor = "Michel Moriniaux";

struct config_t powerBoxConf;
struct status_t powerBoxStatus;

extern String boardSignature;
extern const byte ports2Pin[];
extern const byte port2bin[];

char* queue[QUEUELENGTH];
int queueHead = -1;
int queueCount = 0;

// Machine states
enum FSMStates { stateIdle, stateRead, stateDew, stateSwap };
// PWM port modes
enum PWMModes { variable, switchable, dewHeater, tempFeedback};
// Commands
String line;                              // command buffer
String status;                            // status string buffer

int currentConfAddr = 0;                  // EEPROM address of the current valid config storage block
int portIndex = 0;                        // index of the current port being measured
int portMax;                              // number of ports
int idx = 0;                              // index into the command string
bool haveTemp;                            // stores whether the SHT sensor was found (true)
bool havePress = false;                   // only for BME280
bool dsel = true;                         // we start with dsel HIGH for port 1
int chip = 0;                             // chip index being measured
// time
long int now;                             // now time in millis
long int last;                            // last time in millis
long int lastm;                           // last time we updated the dewheaters in millis

//-----------------------------------------------------------------------
// Utility functions
//-----------------------------------------------------------------------

char* pop() {
  --queueCount;
  DPRINT(F("- pop queueCount="));
  DPRINT(queueCount);
  DPRINT(F(" content="));
  DPRINTLN(queue[queueHead]);
  return queue[queueHead--];
}


void push(char command[MAXCOMMAND]) {
  queueCount++;
  queueHead++;
  DPRINT(F("- push queueCount="));
  DPRINT(queueCount);
  DPRINT(F(" content="));
  strncpy(queue[queueHead], command, MAXCOMMAND);
  DPRINTLN(queue[queueHead]);
}


// check whether to write EEPROM if contents of config are different
//   than what is in the EEPROM at currentConfAddr
// return true if any member is different
bool updateEEPROMCheck( config_t savedConfig ) {
  if ( savedConfig.portStatus != powerBoxConf.portStatus )
    return true;
  for ( int i=0; i < sizeof(powerBoxConf.pwmPorts); i++ ) {
    if ( savedConfig.pwmPorts[i] != powerBoxConf.pwmPorts[i] )
      return true;
    if ( savedConfig.pwmPortMode[i] != powerBoxConf.pwmPortMode[i] )
      return true;
    if ( savedConfig.pwmPortPreset[i] != powerBoxConf.pwmPortPreset[i] )
      return true;
    if ( savedConfig.pwmPortTempOffset[i] != powerBoxConf.pwmPortTempOffset[i] )
      return true;
  }
  DPRINTLN(F("- updateEEPROMCheck False"));
  return false;
}


// Write to the EEPROM if the config has changed
void writeConfigToEEPROM() {
  config_t savedConfig;
  EEPROM.get(currentConfAddr, savedConfig);

  if ( updateEEPROMCheck( savedConfig ) ) {
    DPRINT(F("- writing new config to EEPROM at="));
    // make the saved config obsolete
    EEPROM.write(currentConfAddr, OLDCONFIGFLAG);
    // calculate the new config slot addr
    currentConfAddr = currentConfAddr + sizeof(config_t);
    // check if the new config is going to fit, if not restart at the begining
    if ( currentConfAddr + sizeof(config_t) >= EEPROM.length() ) {
      currentConfAddr = EEPROMCONFBASE;
    }
    DPRINTLN(currentConfAddr);
    // write the new config at the next memory slot
    EEPROM.put(currentConfAddr, powerBoxConf);
  }
}


// Write the new port name to the EEPROM
void writeNameToEEPROM(int port, const String &name) {
  int address;
  char buf[NAMELENGTH];
  char old[NAMELENGTH];

  // determine the EEPROM address
  address = port * NAMELENGTH;
  // get the previous name and make sure we are not wasting write cycles
  EEPROM.get(address, old);
  DPRINT(F("- writeNameToEEPROM Old="));
  DPRINT(old);
  DPRINT(F(" New="));
  name.toCharArray(buf, NAMELENGTH);
  DPRINTLN(buf);
  if (strcmp(old, buf)) {
    DPRINT(F("- writeNameToEEPROM writing="));
    DPRINTLN(buf);
    EEPROM.put(address, buf);
  }
}


// reset config to defaults 
// only called if we did not find a current config
void setDefaults() {
  powerBoxConf.currentData = CURRENTCONFIGFLAG;
  powerBoxConf.portStatus = ALLOFF;
  for ( int i=0; i < sizeof(powerBoxConf.pwmPorts); i++ ) {
    powerBoxConf.pwmPorts[i] = PWMMIN;
    powerBoxConf.pwmPortMode[i] = variable;
    powerBoxConf.pwmPortPreset[i] = PWMMIN;
    powerBoxConf.pwmPortTempOffset[i] = 0;
  }
  currentConfAddr = EEPROMCONFBASE;
  writeConfigToEEPROM();                                   // update values in EEPROM
}


void clearSerialPort() {
  while ( Serial.available() )
    Serial.read();
}


// SerialEvent occurs whenever new data comes in the serial RX.
void serialEvent() {

  // '>' starts the command, '#' ends the command, do not store these in the command buffer
  // read the command until the terminating # character
  char buf[MAXCOMMAND];
  while ( Serial.available() )
  {
    char inChar = Serial.read();
    switch ( inChar )
    {
      case '>':     // soc, reinit line
        // memset(line, 0, MAXCOMMAND);
        line = "";
        idx = 0;
        break;
      case '#':     // eoc
        // line[idx] = '\0';
        line.toCharArray(buf, MAXCOMMAND);
        idx = 0;
        DPRINT(F("- serialEvent push="));
        DPRINT(buf);
        DPRINTLN(F("|"));
        push(buf);
        break;
      default:      // anything else
        if ( idx < MAXCOMMAND - 1) {
          // line[idx++] = inChar;
          line += inChar;
          // DPRINTLN(line);
        }
        break;
    }
  }
}


// SERIAL COMMS
void sendPacket(const String &str) {
  DPRINT(F("- Send: "));
  DPRINTLN(str);
  Serial.print(str);
}


//-----------------------------------------------------------------------
// Port Operations
//-----------------------------------------------------------------------
void getStatusString() {
  // return a status string to the driver with the following info:
  // - a bitmap of port statuses following the boardSignature format
  // the current of each port
  // the in current
  // the in voltage
  // current temperature
  // current humidity
  // 0:0:0:0:0:0:0:0:127:255:195:100:1:1:5.54:5.49:5.42:5.37:5.44:5.49:5.54:5.49:5.39:5.49:5.44:5.37:0.22:0.23:0.07:3.37:0.00:0.00
  // TODO make this modular and based on boardSignature

  // port status
  status = "";
  for ( int i=0; i < 8; i++) {
    status += bitRead(powerBoxConf.portStatus, i);
    status += ":";
  }
  // PWM port duty cycles
  for ( int i=0; i < sizeof(powerBoxConf.pwmPorts); i++) {
    status += powerBoxConf.pwmPorts[i];
    status += ":";
  }
  // the 2 always-on ports
  status += "1:1:";
  // port currents
  for ( int i=0; i < (sizeof(powerBoxStatus.portAmps) / sizeof(float)); i++) {
    status += powerBoxStatus.portAmps[i];
    status += ":";
  }
  // input Amps
  status += powerBoxStatus.inputAmps;
  status += ":";
  // input Volts
  status += powerBoxStatus.inputVolts;
  // Temperatures
  if (haveTemp) {
    status += ":";
    // temperature
    status += powerBoxStatus.temp;
    status += ":";
    // humidity
    status += powerBoxStatus.humid;
    status += ":";
    // dewpoint
    status += powerBoxStatus.dewpoint;
    // pressure
    if (havePress) {
      status += ":";
      status += powerBoxStatus.pressure;
    }
    for ( int i = 1; i < probeCount ; i++ ) {
      status += ":";
      // temperature
      status += powerBoxStatus.tempProbe[i];
    }
  }
}


void switchPortOn(int port) {
  // determine the type of port
  DPRINT(F("- spon port="));
  DPRINTLN(port);
  if ( boardSignature[port] == 's' ) {
    // normal on/off port
    if ( bitRead(powerBoxConf.portStatus, port) == 0x00 ) {
      digitalWrite(ports2Pin[port], HIGH);
      powerBoxConf.portStatus = powerBoxConf.portStatus + port2bin[port];
    }
  }
  if ( boardSignature[port] == 'm' ) {
    // multiplex on/off port
    mcp.digitalWrite(ports2Pin[port], HIGH);
    if ( bitRead(powerBoxConf.portStatus, port) == 0x00 ) {
      powerBoxConf.portStatus = powerBoxConf.portStatus + port2bin[port];
    }
    DPRINTLN(mcp.readGPIO());
  }
  if ( boardSignature[port] == 'p' ) {
    // PWM on/off port
    if (powerBoxConf.pwmPorts[port - boardSignature.indexOf("p")] != PWMMAX ) {
      analogWrite(ports2Pin[port], PWMMAX);
      powerBoxConf.pwmPorts[port - boardSignature.indexOf("p")] = PWMMAX;
    }
  }
  DPRINT(F("- PortStatus="));
  DPRINTLN(powerBoxConf.portStatus);

  // we may have made a change so write the config to EEPROM
  writeConfigToEEPROM();
}


void switchPortOff(int port) {
  // determine the type of port
  DPRINT(F("- spoff port="));
  DPRINTLN(port);
  if ( boardSignature[port] == 's' ) {
    // normal on/off port
    if ( bitRead(powerBoxConf.portStatus, port) == 0x01 ) {
      digitalWrite(ports2Pin[port], LOW);
      powerBoxConf.portStatus = powerBoxConf.portStatus - port2bin[port];
    }
  }
  if ( boardSignature[port] == 'm' ) {
    // multiplex on/off port
    mcp.digitalWrite(ports2Pin[port], LOW);
    if ( bitRead(powerBoxConf.portStatus, port) == 0x01 ) {
      powerBoxConf.portStatus = powerBoxConf.portStatus - port2bin[port];
    }
    DPRINTLN(mcp.readGPIO());
  }
  if ( boardSignature[port] == 'p' ) {
    // PWM on/off port
    if (powerBoxConf.pwmPorts[port - boardSignature.indexOf("p")] != PWMMIN ) {
      analogWrite(ports2Pin[port], PWMMIN);
      powerBoxConf.pwmPorts[port - boardSignature.indexOf("p")] = PWMMIN;
    }
  }
  DPRINT(F("- PortStatus="));
  DPRINTLN(powerBoxConf.portStatus);
  // we may have made a change so write the config to EEPROM
  writeConfigToEEPROM();
}


void shutdownAllPorts() {
  for ( int i=0; i < boardSignature.length(); i++) {
    if ( boardSignature[i] == 's' ) {
      // normal on/off port
      if ( bitRead(powerBoxConf.portStatus, i) == 1 ) {
        digitalWrite(ports2Pin[i], LOW);
        powerBoxConf.portStatus = powerBoxConf.portStatus - port2bin[i];
      }
    }
    if ( boardSignature[i] == 'm' ) {
      // multiplex on/off port
      if ( bitRead(powerBoxConf.portStatus, i) == 1 ) {
        mcp.digitalWrite(ports2Pin[i], LOW);
        powerBoxConf.portStatus = powerBoxConf.portStatus - port2bin[i];
      }
    }
    if ( boardSignature[i] == 'p' ) {
      // PWM on/off port
      if (powerBoxConf.pwmPorts[i - boardSignature.indexOf("p")] != PWMMIN) {
        analogWrite(ports2Pin[i], PWMMIN);
        powerBoxConf.pwmPorts[i - boardSignature.indexOf("p")] = PWMMIN;
      }
    }
  }
  // we may have made a change so write the config to EEPROM
  writeConfigToEEPROM();
}


void setPWMPortLevel(int port, int level) {
  if ( boardSignature[port] == 'p' ) {
    // PWM on/off port
    if (powerBoxConf.pwmPorts[port - boardSignature.indexOf("p")] != level) {
      analogWrite(ports2Pin[port], level);
      powerBoxConf.pwmPorts[port - boardSignature.indexOf("p")] = level;
    }
    // we may have made a change so write the config to EEPROM
    writeConfigToEEPROM();
  }
}


// same function but don't write the EEPROM
void setDewPortLevel(int port, int level) {
    // PWM on/off port
    if ( boardSignature[port] == 'p' ) {
      analogWrite(ports2Pin[port], level);
	} 
}


void swapPorts() {
  // when the controller starts
  // portIndex = 0
  // DSEL = HIGH
  // MUX0=MUX1=MUX2=0
  // this points to the first logical port and output 2 of the first BTS7008 switch
  // portIndex starts at 0 but port numbers at 1 <- TODO stop this BS, do it in the UI

  // increment portIndex
  portIndex++;
  // rollover portIndex if we've reached the end
  if ( portIndex >= portMax )
    portIndex = 0;

  // each time we call swapPorts() we need to inverse DSEL except for the 
  // always on ports but since there are 2 of them we don't care
  dsel = !dsel;
  digitalWrite(DSEL, dsel);

  // every even portIndex we need to change the mux to the next value
  if ( (portIndex % 2) == 0 )
    chip++;
  // dirty ugly hack for our board but no good for modular hardware
  if ( portIndex == 13 )
    chip++;
  // rollover the chip if we are beyond the max
  if ( chip > portMax / 2 )
    chip = 0;
  // determine the values of MUXx from chip and write them
  digitalWrite(MUX0, bitRead(chip, 0));
  digitalWrite(MUX1, bitRead(chip, 1));
  digitalWrite(MUX2, bitRead(chip, 2));
  // done
#ifdef DEBUG
  //char buf[40];
  //sprintf(buf, "- swap: chip=%d, port=%d, dsel=%d", chip, portIndex, dsel);
  //DPRINTLN(buf);
  //sprintf(buf, "- mux: c=%d, 0=%d, 1=%d, 2=%d", chip, bitRead(chip, 0), bitRead(chip, 1), bitRead(chip, 2));
  //DPRINTLN(buf);
#endif
}


//-----------------------------------------------------------------------
// Dew Control
//-----------------------------------------------------------------------
void adjustDewHeaters() {
  int pwmPort;
  int pwmPortNum = 0;
  int level;

  pwmPortNum = sizeof(powerBoxConf.pwmPorts);
  // PWM ports start at boardSignature.indexOf("p")
  //
  for ( int port=boardSignature.indexOf("p"); port < pwmPortNum + boardSignature.indexOf("p"); port++) {

    // Zero based index for probes 
    //
    int index = port - boardSignature.indexOf("p");
    if ( powerBoxConf.pwmPortMode[index] == dewHeater ) {
      if (powerBoxStatus.temp < powerBoxStatus.dewpoint + powerBoxConf.pwmPortTempOffset[index]) {
        // As of now powerBoxConf.pwmPortPreset is not being initialized anywhere. Use powerBoxConf.pwmPorts for now 
        // TBD: do something meaningful with powerBoxConf.pwmPortPreset
        //
        setDewPortLevel(port, int(powerBoxConf.pwmPorts[index]));
      } else if ( powerBoxStatus.temp > powerBoxStatus.dewpoint + powerBoxConf.pwmPortTempOffset[index]) {
        setDewPortLevel(port, PWMMIN);;
      }
    }
    if ( powerBoxConf.pwmPortMode[index] == tempFeedback ) {
      if ( powerBoxStatus.tempProbe[index] < powerBoxStatus.dewpoint + powerBoxConf.pwmPortTempOffset[index]) {
        pid[port- boardSignature.indexOf("p")].setpoint(powerBoxStatus.dewpoint + powerBoxConf.pwmPortTempOffset[index]);
        level = int(pid[index].compute(powerBoxStatus.tempProbe[index]));
        DPRINT(F("tempfeedbck set port "));
        DPRINT(port);
        DPRINT(F(" power: "));
        DPRINTLN(level);
        setDewPortLevel(port, level);
      }
    }
  }
}
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
void loop() {
  static byte FSMState = stateIdle;
  
  if ( queueCount >= 1 )                 // check for serial command
  {
    processSerialCommand();
  }
  switch (FSMState)
  {
    case stateIdle:
      // wait REFRESH milliseconds between Read cycles
      now = millis();
      if ( now > last + REFRESH )
        FSMState = stateRead;
      else
        FSMState = stateIdle;
      break;

    case stateRead:
      // lets read the values on our Analog ports
      // first the input
      // equations are given by the hardware implementation and the datasheets
      // to be truly modular (ie have the board.h be the SoT for the HW implementation)
      // we should use macros defined board.h
      powerBoxStatus.inputVolts = (( analogRead(VSIN) * (VCC / 1023.0) ) * RDIVIN ) / RDIVOUT;
      powerBoxStatus.inputAmps = (( analogRead(ISIN) * (VCC / 1023.0) ) - (VCC/2)) * 1000.0 / KINIS;
      // if input is above MAXINVOLTS then we need to shutdown power to all downstreams
      if ( powerBoxStatus.inputVolts > MAXINVOLTS )
        shutdownAllPorts();
      // next read the output current for the current port
      switch ( boardSignature[portIndex] ) {
        case 's':
        case 'm':
        case 'p':
          powerBoxStatus.portAmps[portIndex] = ( analogRead(ISOUT) * (VCC / 1023.0) ) * KILIS / ROUTIS;
          break;
        case 'a':
          powerBoxStatus.portAmps[portIndex] = (( analogRead(ISOUT) * (VCC / 1023.0)) - (VCC/2)) * 1000.0 / KOUTIS;
          break;
        default:
          break;
      }

#ifdef DEBUG
      //char buf[50];
      //sprintf(buf, "- loop: iV=%d, iI=%d, oI=%d, p=%d, mem=%d", analogRead(VSIN), analogRead(ISIN), analogRead(ISOUT), portIndex, freeMemory());
      //DPRINTLN(buf);
      //DPRINTLN(mcp.readGPIO());
      memfree = freeMemory();
      if (memfree != prevmemfree) {
        prevmemfree = memfree;
        DPRINT(F("Mem: "));
        DPRINTLN(memfree);
      }
#endif
      FSMState = stateDew;
      now = millis();
      last = now;
      break;

    case stateDew:
      // adjust PWM ports for dew heater control, do this every minute only
      now = millis();
      if ( now > lastm + (TEMPITVL * 60000) ) {
        // get temp and humidity
        if ( haveTemp ) {
          switch (powerBoxStatus.tempProbeType[0]) {
            case SHT31_0x44:
              sht31.begin(0x44);
              sht31.readBoth(&powerBoxStatus.temp, &powerBoxStatus.humid);
              break;
            case SHT31_0x45:
              sht31.begin(0x45);
              sht31.readBoth(&powerBoxStatus.temp, &powerBoxStatus.humid);
              break;
            case AHT10:
              sensors_event_t temp;
              sensors_event_t humid;
              aht10.getEvent(&humid, &temp);
              powerBoxStatus.temp = temp.temperature;
              powerBoxStatus.humid = humid.relative_humidity;
              break;
            case BME280_0x76:
              bme.begin(0x76);
              powerBoxStatus.temp = bme.readTemperature();
              powerBoxStatus.humid = bme.readHumidity();
              powerBoxStatus.pressure = bme.readPressure() / 100.00F;
              break;
            case BME280_0x77:
              bme.begin(0x77);
              powerBoxStatus.temp = bme.readTemperature();
              powerBoxStatus.humid = bme.readHumidity();
              powerBoxStatus.pressure = bme.readPressure() / 100.00F;
              break;
          }
          powerBoxStatus.tempProbe[0] = powerBoxStatus.temp;
          powerBoxStatus.dewpoint = powerBoxStatus.temp - ((100 - powerBoxStatus.humid) / 5);

          // cycle through the other sensors to get the temperatures for the PWM ports
          for ( int i = 1 ; i < probeCount ; i++ ) {
            imux.setPort(powerBoxStatus.tempProbePort[i]);
            switch (powerBoxStatus.tempProbeType[i]) {
              case SHT31_0x44:
                sht31.begin(0x44);
                powerBoxStatus.tempProbe[i] = sht31.readTemperature();
                break;
              case SHT31_0x45:
                sht31.begin(0x45);
                powerBoxStatus.tempProbe[i] = sht31.readTemperature();
                break;
              case AHT10:
                sensors_event_t temp;
                sensors_event_t humid;
                aht10.getEvent(&humid, &temp);
                powerBoxStatus.tempProbe[i] = temp.temperature;
                break;
              case BME280_0x76:
                bme.begin(0x76);
                powerBoxStatus.tempProbe[i] = bme.readTemperature();
                break;
              case BME280_0x77:
                bme.begin(0x77);
                powerBoxStatus.tempProbe[i] = bme.readTemperature();
                break;
            }
          }
        }
#ifdef DEBUG
        DPRINT(F(" Status: "));
        getStatusString();
        DPRINTLN(status);
#endif
        adjustDewHeaters();
        lastm = now;
      }
      FSMState = stateSwap;
      break;

    case stateSwap:
      // lets swap the measured port
      swapPorts();
      FSMState = stateIdle;
      break;

    default:
      FSMState = stateIdle;
      break;
  }

}

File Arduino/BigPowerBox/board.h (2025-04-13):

/*-----------------------------------------------------------------------
 * BigPowerBox Board configuration
 * License: GPLv3
 * Michel Moriniaux, 2023
-----------------------------------------------------------------------*/
#ifndef board_h
#define board_h

#include <Arduino.h>
#include "mydefines.h"

// Board signature
//  s: arduino addressable switchable port
//  m: multiplexed switchable port
//  p: pwm port
//  a: Allways-On port
// the following are optional and only appear if they are plugged into the device
//  t: temperature probe
//  h: humidity probe
//  f: temp + humidity probe
//  g: temp + humid + press probe
// always-on ports always last followed by t then h
String boardSignature = "mmmmmmmmppppaa";
// status string
// 0:0:0:0:0:0:0:0:127:255:195:100:1:1:15.54:15.49:15.42:15.37:15.44:15.49:15.54:15.49:15.39:15.49:15.44:15.37:10.22:10.23:10.07:13.37:-10.00:100.00:-10.00
#define STATUSSIZE      200             // size of thebuffer to hold the status line

//-----------------------------------------------------------------------
// EEPROM structures
//-----------------------------------------------------------------------
//      0       7  15
//      -------------
//    0|PORTNAME 1   |
//   16|PORTNAME 2   |
//    ....
//  208|PORTNAME 14  |
//  224|-------------|
//  ...| config      |
//  ...| space       |
// 1013|             |
//     ---------------

// there are 2 types of config values we want to store in EEPROM
// the first struct is rarely modified so it will live in the first 224 bytes of the EEPROM
// we believe that these will be seldom modified so we can live with the 100k writes 
// limitation of the EEPROM
// Configuration struct to store long lived configs in EEPROM

// The second struct will be modified at each change of a port status so might happen a couple
// times per session. This struct will use the remaining EEPROM space and be written at a
// differnet address of that space at each write. validdata will be chosen so that it has a
// low probability of collisions with other values in the struct.
// Configuration struct to store regularly changed configs in EEPROM
// Struct is 6 bytes long
// IMPROVE: do a dynamic declaration of this struct by using BoardSignature and making portPwm an array
struct config_t {
  byte  currentData;                      // if this is CURRENTCONFIGFLAG then data is valid
  byte  portStatus;                       // bitmap of all port statuses (0: Off, 1: On)
  byte  pwmPorts[4];                      // pwm value of ports 9-12 (0: Off, 255: On or 1: On if port in 's' mode)
  byte  pwmPortMode[4];                   // operation mode of the PWM ports (enum PWMModes)
  byte  pwmPortPreset[4];                 // last max value of the port, allows to store a preset
  byte  pwmPortTempOffset[4];             // adjustable temperature offset for the PWM port in mode 3
};

struct status_t {
    float portAmps[14];                   // size of array must be equal to boardSignature.length() this holds the current for each port
    float inputAmps;
    float inputVolts;
    float temp;
    float humid;
    float dewpoint;
    float pressure;
    float tempProbe[5];                   // tempearture reading in C.
    byte  tempProbePort[5];               // i2c muc port on which the probe is found, 255 is used for non mux.
    byte  tempProbeType[5];               // type of probe found. limit them to 5 more would be overkill, like 640k RAM
};

//-----------------------------------------------------------------------
// Digital output pins
//-----------------------------------------------------------------------
// ports 1 - 8 are addresed via port A of an MCP23017 IC.
// they use the adafruit library and are driven by I2C commands
#define PORT1EN             0             // GPA0 en/disable port 1
#define PORT2EN             1             // GPA1 en/disable port 2
#define PORT3EN             2             // GPA2 en/disable port 3
#define PORT4EN             3             // GPA3 en/disable port 4
#define PORT5EN             4             // GPA4 en/disable port 5
#define PORT6EN             5             // GPA5 en/disable port 6
#define PORT7EN             6             // GPA6 en/disable port 7
#define PORT8EN             7             // GPA7 en/disable port 8
// ports 9 - 12 are PWM ports and are driven by the Arduino
#define PORT9EN             3             // D3 PWM port 9
#define PORT10EN            5             // D5 PWM port 10
#define PORT11EN            6             // D6 PWM port 11
#define PORT12EN            9             // D9 PWM port 12

const byte ports2Pin[12] = {PORT1EN, PORT2EN, PORT3EN, PORT4EN, PORT5EN, PORT6EN, PORT7EN, PORT8EN, PORT9EN, PORT10EN, PORT11EN, PORT12EN};
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

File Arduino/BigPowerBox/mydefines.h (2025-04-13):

/*-----------------------------------------------------------------------
 * BigPowerBox Definitions
 * License: GPLv3
 * Michel Moriniaux, 2023
-----------------------------------------------------------------------*/

#ifndef myDefines_h
#define myDefines_h

#include <Arduino.h>

//-----------------------------------------------------------------------
// Constant Definitions
//-----------------------------------------------------------------------
#define MAXINVOLTS          14.7          // maximum allowed volts In, shutdown all output ports if exceeded
#define REFRESH             200           // read port values every REFRESH milliseconds
#define TEMPITVL            1             // adjust dew heaters every TEMPITVL minutes
#define SERIALPORTSPEED     9600          // 9600, 14400, 19200, 28800, 38400, 57600
#define QUEUELENGTH         5             // number of commands that can be saved in the serial queue
#define MAXCOMMAND          21            // max length of a command
#define NAMELENGTH          16            // max lenght of a port name
#define EOFSTR              '\n'
#define EOCOMMAND           '#'           // defines the end character of a command
#define SOCOMMAND           '>'           // defines the start character of a command
#define CURRENTCONFIGFLAG   99            // the config struct has a currentdata field indicating whether it is in use
#define OLDCONFIGFLAG       0             // currentdata set this when eeprom structure is no longer in use
#define PWMMIN              0
#define PWMMAX              255
#define KP                  7.0F
#define KI                  0.3F
#define KD                  0.0F
// port states bitmap
#define ALLOFF              0             // 00000000 ALL OFF
#define ALLON               255           // 11111111 ALL ON
//-----------------------------------------------------------------------
// DEBUGGING
//-----------------------------------------------------------------------
//#define DEBUG 1
#ifdef DEBUG
#define DPRINT(...) Serial.print(__VA_ARGS__)
#define DPRINTLN(...) Serial.println(__VA_ARGS__)
#else
#define DPRINT(...)
#define DPRINTLN(...)
#endif

#endif

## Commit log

2023-03-12 %v buck converters
2023-03-12 Enclosure files
    [Box.stl, Lid.stl]
2023-03-20 PCB bug correction
    prevent backfeed of USB power through regulator into power section by adding a diode.
    When 12v not present any load on the output power ports could overload the USB port and have its fuse blow or worse damage the PC USB port
    [BOM_PCB_BigPowerBox.csv, Box.stl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]
2023-03-21 Update README.md
    updated PCB text with reasons for component choices
2023-03-31 Dew Heater features
2023-04-30 Added support for dew heaters
    - added support for an external i2c multiplexer and additional temperature probes ( AHT10 and SHT31 addresses )
    - added support for control of dew heaters on the PWM ports. 2 modes are available: simple dewpoint activation and temperature probe PID control. CAVEAT: Kp,Ki, Kd are roughly tuned at this point
    - refactored code to allow these changes
2023-04-30 added i2c mux PCB design
    i2c mux PCB design
2023-05-03 bug fixes
    adjusted cutoff voltage to be compatible with LiFePo4 chargers 14.7V
    PWM port number description was not incrementing
    [mydefines.h]
2024-05-27 fixed port index as per issue #5
    [BigPowerBox.ino]
2024-05-27 fix attemps to issue 6
    [BigPowerBox.ino]
2024-05-29 Fix issue#6: fix dew heater and temperature control
    [BigPowerBox.ino]
2024-06-09 Initial indigo driver release
2024-06-10 1. Fix hang during first time launch 2. Add driver information 3. Readability changes 4. Minor tweaks
    [indigo_aux_pbex.c]
2024-06-11 1. Support temperature offsets 2. Improved UI 3. Minor cleanup
2024-06-11 indigo driver for BigPowerBox
2024-06-13 fix loss of properties
    [indigo_aux_pbex.c]
2024-06-13 1. Added validation 2. Fixed compiler warnings
    [indigo_aux_pbex.c]
2025-04-13 bug corrections and better name handling
    [BigPowerBox.ino, mydefines.h]
